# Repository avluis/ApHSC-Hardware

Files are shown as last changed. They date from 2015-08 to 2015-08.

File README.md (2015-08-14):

# ApHSC - Hardware
# Eagle CAD files for the ApHSC
  By: [Luis E Alvarado](mailto:admin@avnet.ws)
  
  [Software](https://github.com/avluis/ApHSC) | 
  [Hardware](https://github.com/avluis/ApHSC-Hardware)
  
# Purpose:
	To drive a ComfortHeat "Automotive Carbon Fiber Seat Heaters"
  	by Rostra with the stock control panel of a vehicle, in my case, a 2011 Suzuki Kizashi
  [Rostra Kit: 250-1872 - Universal Kit, Double thumb-dial Switch](http://www.rostra.com/manuals/250-1870_Form5261.pdf)

# Screenshots:
  Rev 4 - Front
  Rev 4 - Rear

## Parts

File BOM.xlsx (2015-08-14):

Item # | Ref Des | Description | Qty | Manufacture | Mfg Part# | Digi-Key Part# | Package | Type
1 | C1 | CAP CER 0.33UF 50V 10% X5R 0603 | 1 | TDK | CGA3E3X5R1H334K080AB | 445-12504-1-ND | 0603 | SMD
2 | C2 | CAP CER 0.1UF 50V 10% X7R 0603 | 1 | TDK | CGA3E2X7R1H104K080AA | 445-5666-1-ND | 0603 | SMD
3 | C3 | CAP CER 470PF 50V 10% X7R 0603 | 1 | Kemet | C0603C471K5RACTU | 399-1075-1-ND | 0603 | SMD
4 | C4 | CAP CER 0.1UF 16V 10% X7R 0603 | 1 | Murata | GRM188R71C104KA01D | 490-1532-1-ND | 0603 | SMD
5 | R1, R2 | RES SMD 15K OHM 5% 1/10W 0603 | 2 | Yageo | RC0603JR-0715KL | 311-15KGRCT-ND | 0603 | SMD
6 | R3, R4, R5 | RES SMD 10K OHM 5% 1/10W 0603 | 3 | Yageo | RC0603JR-0710KL | 311-10KGRCT-ND | 0603 | SMD
7 | R6, R7 | RES SMD 1K OHM 5% 1/10W 0603 | 2 | Yageo | RC0603JR-071KL | 311-1.0KGRCT-ND | 0603 | SMD
8 | L | LED CHIPLED BLUE 470NM 0603 SMD | 1 | OSRAM | LB Q39G-L2OO-35-1 | 475-2816-1-ND | 0603 | SMD
9 | ON | LED CHIPLED 633NM RED 0603 SMD | 1 | OSRAM | LS Q976-NR-1 | 475-2512-1-ND | 0603 | SMD
10 | U1 | IC MCU 8BIT 32KB FLASH 32TQFP | 1 | Atmel | ATMEGA328P-AU | ATMEGA328P-AU-ND | 32-TQFP | SMD
11 | U2 | IC REG LDO 5V 0.5A SOT223 | 1 | Texas Instruments | UA78M05IDCYR | 296-17616-1-ND | SOT223 | SMD
12 | U3 | IC MOSFET DVR 7CH 40V 16SOIC | 1 | Texas Instruments | TPL7407LDR | 296-37284-1-ND | 16-SOIC | SMD
13 | U4 | IC SOURCE DRIVER 8CHAN 20SOIC | 1 | Allegro | A2982SLWTR-T | 620-1127-1-ND | 20-SOIC W | SMD
14 | XTAL | CER RESONATOR 16.0MHZ SMD | 1 | Murata | CSTCE16M0V53-R0 | 490-1198-1-ND | 3-SMD | SMD

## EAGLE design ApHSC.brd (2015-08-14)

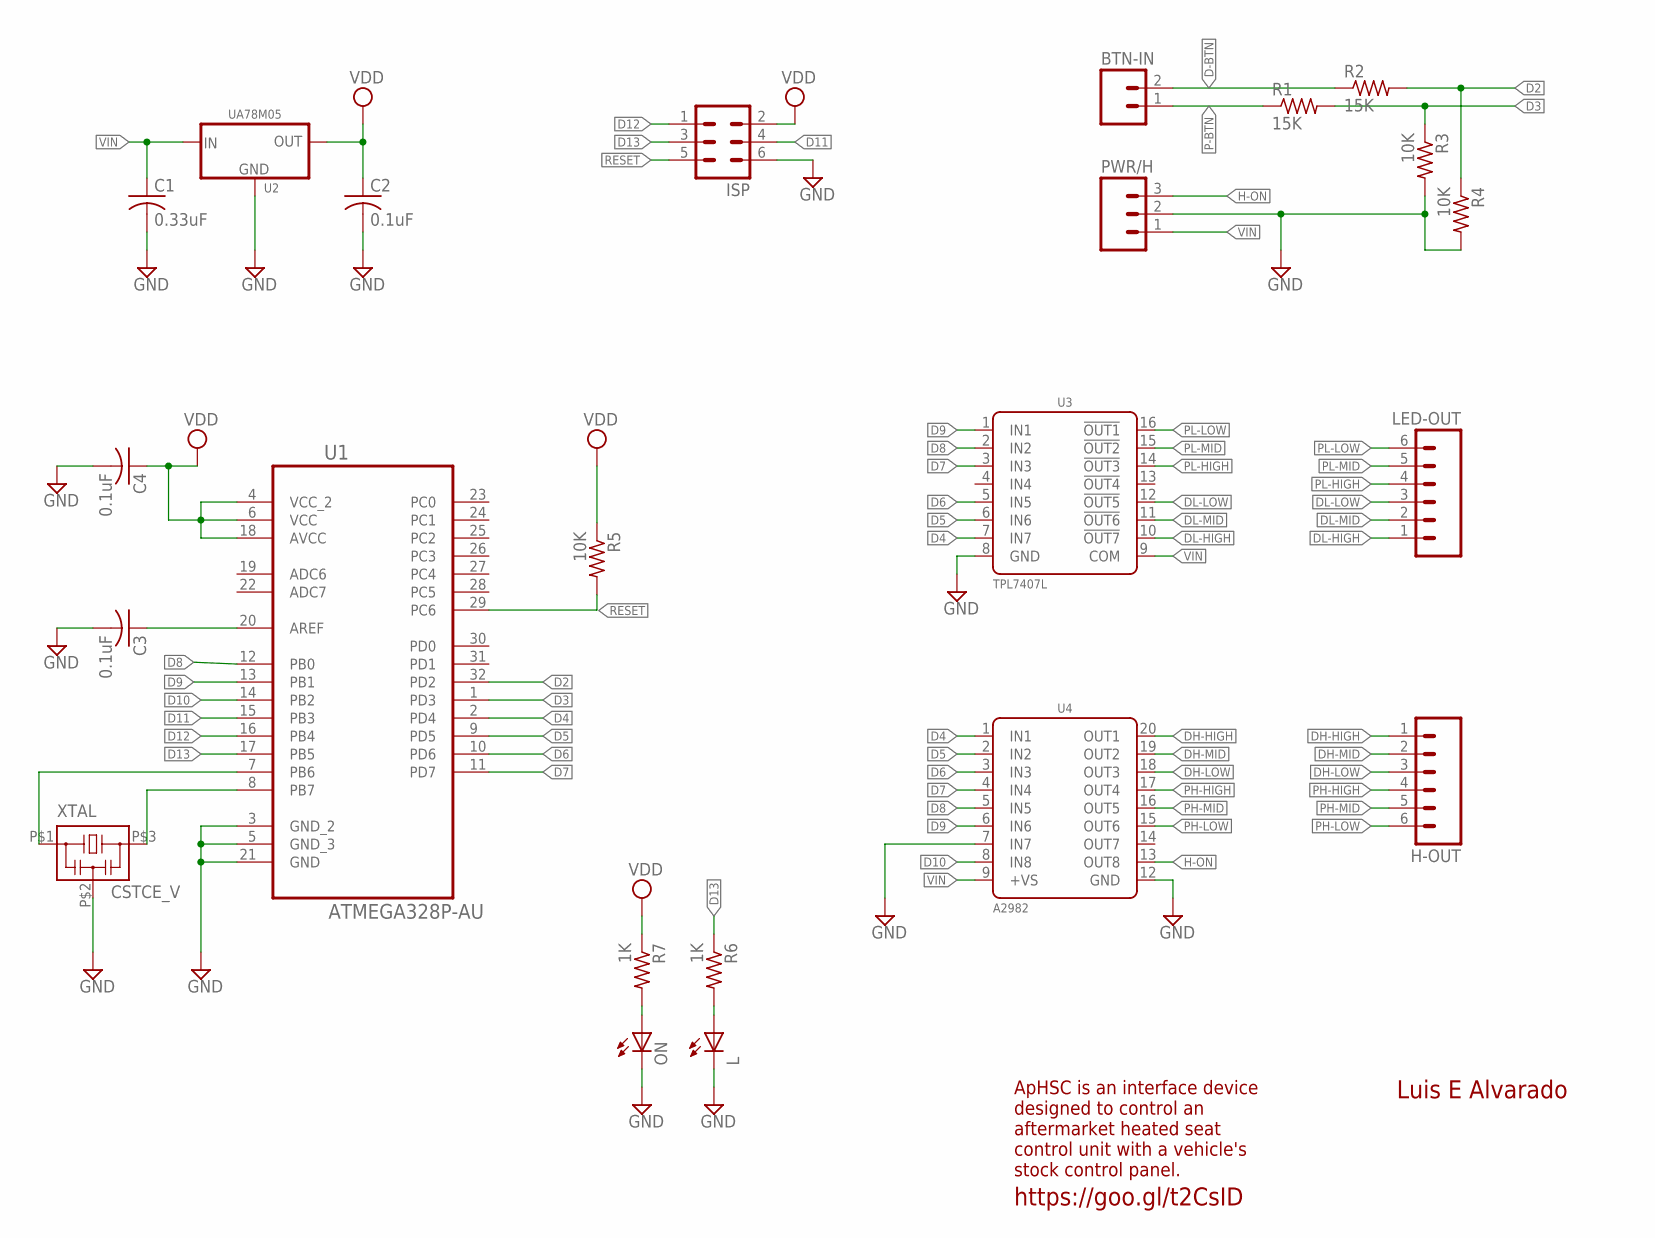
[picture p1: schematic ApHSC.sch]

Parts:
BTN-IN: M02PTH; 1X02
C1: 0.33uF; C0603
C2, C3, C4: 0.1uF; C0603
H-OUT: M06SIP; 1X06
ISP: MA03-2
L: LEDCHIP-LED0603; CHIP-LED0603
LED-OUT: M06SIP; 1X06
ON: LEDCHIP-LED0603; CHIP-LED0603
PWR/H: M03PTH; 1X03
R1, R2: 15K; R0603
R3, R4, R5: 10K; R0603
R6, R7: 1K; R0603
U1: ATMEGA328P-AU; QFP80P900X900X120-32N
U2: UA78M05; SOT223
U3: TPL7407L; SOIC16N
U4: A2982; SOIC20W
XTAL: CSTCE_V

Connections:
AREF: C3.1, U1.20 (AREF)
D2: R2.2, R4.1, U1.32 (PD2)
D3: R1.2, R3.1, U1.1 (PD3)
D4: U1.2 (PD4), U3.7 (IN7), U4.1 (IN1)
D5: U1.9 (PD5), U3.6 (IN6), U4.2 (IN2)
D6: U1.10 (PD6), U3.5 (IN5), U4.3 (IN3)
D7: U1.11 (PD7), U3.3 (IN3), U4.4 (IN4)
D8: U1.12 (PB0), U3.2 (IN2), U4.5 (IN5)
D9: U1.13 (PB1), U3.1 (IN1), U4.6 (IN6)
D10: U1.14 (PB2), U4.8 (IN8)
D11: ISP.4, U1.15 (PB3)
D12: ISP.1, U1.16 (PB4)
D13: ISP.3, R6.1, U1.17 (PB5)
D-BTN: BTN-IN.2, R2.1
DH-HIGH: H-OUT.1, U4.20 (OUT1)
DH-LOW: H-OUT.3, U4.18 (OUT3)
DH-MID: H-OUT.2, U4.19 (OUT2)
DL-HIGH: LED-OUT.1, U3.10 (!OUT7)
DL-LOW: LED-OUT.3, U3.12 (!OUT5)
DL-MID: LED-OUT.2, U3.11 (!OUT6)
GND: C1.2, C2.2, C3.2, C4.2, ISP.6, L.C, ON.C, PWR/H.2, R3.2, R4.2, U1.3 (GND_2), U1.5 (GND_3), U1.21 (GND), U2.2 (GND), U3.8 (GND), U4.7 (IN7), U4.12 (GND), XTAL.P$2 (2)
H-ON: PWR/H.3, U4.13 (OUT8)
unnamed: L.A, R6.2
unnamed: ON.A, R7.2
P-BTN: BTN-IN.1, R1.1
PB6: U1.7 (PB6), XTAL.P$1 (1)
PB7: U1.8 (PB7), XTAL.P$3 (3)
PH-HIGH: H-OUT.4, U4.17 (OUT4)
PH-LOW: H-OUT.6, U4.15 (OUT6)
PH-MID: H-OUT.5, U4.16 (OUT5)
PL-HIGH: LED-OUT.4, U3.14 (!OUT3)
PL-LOW: LED-OUT.6, U3.16 (!OUT1)
PL-MID: LED-OUT.5, U3.15 (!OUT2)
RESET: ISP.5, R5.2, U1.29 (PC6)
VDD: C2.1, C4.1, ISP.2, R5.1, R7.1, U1.4 (VCC_2), U1.6 (VCC), U1.18 (AVCC), U2.3 (OUT)
VIN: C1.1, PWR/H.1, U2.1 (IN), U3.9 (COM), U4.9 (+VS)

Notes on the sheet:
Luis E Alvarado
ApHSC is an interface device designed to control an aftermarket heated seat control unit with a vehicle's stock control panel.
https://goo.gl/t2CsID

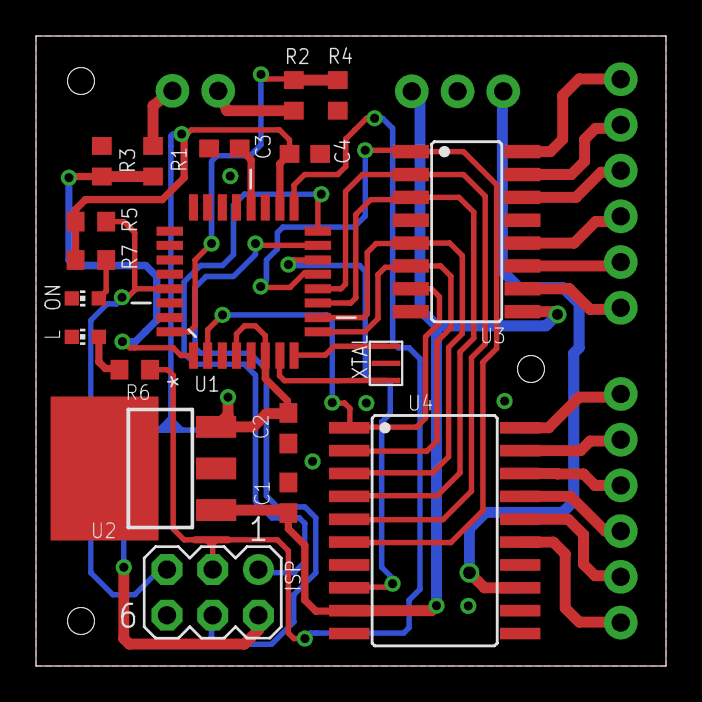
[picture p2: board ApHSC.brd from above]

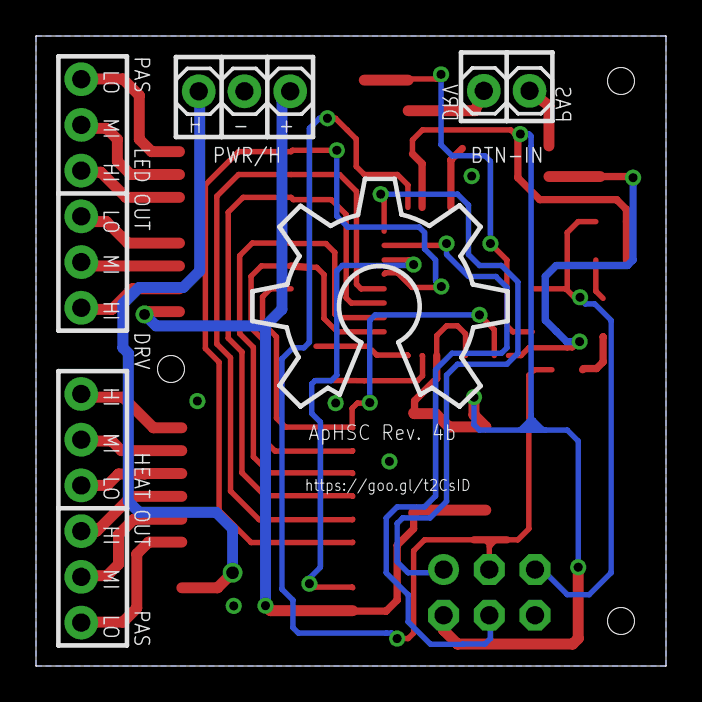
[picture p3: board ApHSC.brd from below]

Board: 2 copper layers, 35.0 x 35.0 mm, 24 parts (5 on the bottom side), 36 nets.

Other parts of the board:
U$1: OSHW_10X500_NOTEXT

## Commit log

2015-02-08 Common Arduino library
2015-02-08 Schematic & Board - rev 2 https://oshpark.com/shared_projects/5AbDykNL
    [Arduino_Heated_Seats_Controller.brd, Arduino_Heated_Seats_Controller.sch]
2015-02-08 Revision 2 schematic pdf
2015-04-29 Initial work on rev3 underway (time for some sleep).
    [Arduino_Heated_Seats_Controller.brd, Arduino_Heated_Seats_Controller.sch]
2015-04-30 ULN2003A replaced with ULN2803A (both from Texas Instruments - but with one more input, cheaper and actually available without jumping to eBay). Work on replacing the M54564P underway.
    [Arduino_Heated_Seats_Controller.sch]
2015-04-30 Revert "ULN2003A replaced with ULN2803A (both from Texas Instruments - but with one more input, cheaper and actually available without jumping to eBay)."
    This reverts commit adf95428dccab3bb593bcfff33bcf90c1b5228b2.
    [Arduino_Heated_Seats_Controller.sch]
2015-04-30 Settled for an ULN2003A (compatible with Toshiba variant) and the TD62783AFG (from Toshiba as well).
    [Arduino_Heated_Seats_Controller.sch]
2015-04-30 Additional pads for TX and RX (if needed).
    [Arduino_Heated_Seats_Controller.sch]
2015-04-30 Initial layout & routing complete - started work on silk layer (traces: need to tweak width on certain traces to handle load current).
    [Arduino_Heated_Seats_Controller.brd]
2015-04-30 Swapped MIC5219B for uA78M05I to handle higher input voltage (and lower operating environment temps). Swapped a few capacitors (removed polarized 0.1uF on regulator output). Removed a few pads not ne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
    [Arduino_Heated_Seats_Controller.sch]
2015-05-01 A few more layout changes to accommodate part changes and physical part dimensions. Still a few more things to add (drills for mounting, traces to widen, silk to add) but nothing major.
    [Arduino_Heated_Seats_Controller.brd]
2015-05-02 Added reset label to trace on reset pin.
    [Arduino_Heated_Seats_Controller.sch]
2015-05-02 More tweaks to traces (hopefully final). More silk labels (on pins as well). Holes (for mounting). And anything else I might have forgotten - looks ready to send to fab for electrical test.
    [Arduino_Heated_Seats_Controller.brd]
2015-06-08 Bill of Materials - prepping for a v4 - reverting to a single sided for easier solder/reflow.
2015-06-08 Changes: Removed test pins.
    Corrections:
    Removed ground on ULN2003A pin 9.
    GND on ULN2003A is pin 8 (pin 9 is COMMON/E).
    [Arduino_Heated_Seats_Controller.sch]
2015-06-09 Changes so far - commit before tweaking trace width and misc.
    [Arduino_Heated_Seats_Controller.brd]
2015-06-10 Final tweaks and changes - off to the fab house.
    [Arduino_Heated_Seats_Controller.brd]
2015-06-10 Oops, drill in the wrong location - fixed - v4 is ready for OSH Park (for real this time). Plans for v5 in the works - simply to replace v3. v4 and v5 will be interchangeable (only difference will be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
    [Arduino_Heated_Seats_Controller.brd]
2015-06-10 ERC check.
    [Arduino_Heated_Seats_Controller.sch]
2015-06-10 Additional silkscreen and trace width tweaks before sending to OSH Park (still v4).
    [Arduino_Heated_Seats_Controller.brd]
2015-06-10 Small position tweak to allow ground pour around connectors.
    [Arduino_Heated_Seats_Controller.brd]
2015-08-03 Library error - need to make sure the rest of my libraries are correct are well.
    [Arduino_Heated_Seats_Controller.brd, Arduino_Heated_Seats_Controller.sch]
2015-08-03 More patching.
    [Arduino_Heated_Seats_Controller.brd, Arduino_Heated_Seats_Controller.sch]
2015-08-03 Grounding unused input pins (compatibility with A2982SLWTR-T). Tweak routing and vias.
    [Arduino_Heated_Seats_Controller.brd, Arduino_Heated_Seats_Controller.sch]
2015-08-04 Swapped ATMega from unknown library with Element14 library. Moved silkscreen (web address) to other side of board.
    [Arduino_Heated_Seats_Controller.brd, Arduino_Heated_Seats_Controller.sch]
2015-08-05 Enough changes to warrant a minor revision bump. Equivalent parts have been selected for testing - will need to update design if tests are good. Current design should be compatible with selected part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
    [Arduino_Heated_Seats_Controller.brd, Arduino_Heated_Seats_Controller.sch]
2015-08-12 Changes from freelancer.com - lovely~
    [Arduino_Heated_Seats_Controller.brd, Arduino_Heated_Seats_Controller.sch]
2015-08-12 Tweaking silkscreen.
    [Arduino_Heated_Seats_Controller.brd]
2015-08-12 Files received back from freelancer.com (before my tweaks and merge).
    [Arduino_Heated_Seats_Controller.brd, Arduino_Heated_Seats_Controller.sch]
2015-08-12 Tweaking a few things.
    [Arduino_Heated_Seats_Controller.brd, Arduino_Heated_Seats_Controller.sch]
2015-08-14 Renamed files.
    [ApHSC.brd, ApHSC.sch]
2015-08-14 Minor stylistic edits.
    [ApHSC.sch]
2015-08-14 BOM text file replaced for excel sheet. BOM complete with Digi-Key part numbers.
    [BOM.xlsx]
2015-08-14 Small layout changes - tweaked position of vias and silkscreen.
    [ApHSC.brd]
2015-08-14 More silkscreen tweaks. Moved Heat/LED silkscreen to bottom layer.
    [ApHSC.brd, ApHSC.sch]

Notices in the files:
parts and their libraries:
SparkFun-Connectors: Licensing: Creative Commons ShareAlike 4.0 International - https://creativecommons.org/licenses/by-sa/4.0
